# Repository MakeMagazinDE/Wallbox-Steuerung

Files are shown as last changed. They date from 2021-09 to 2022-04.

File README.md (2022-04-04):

GitHub Logo

Maker Media GmbH

***

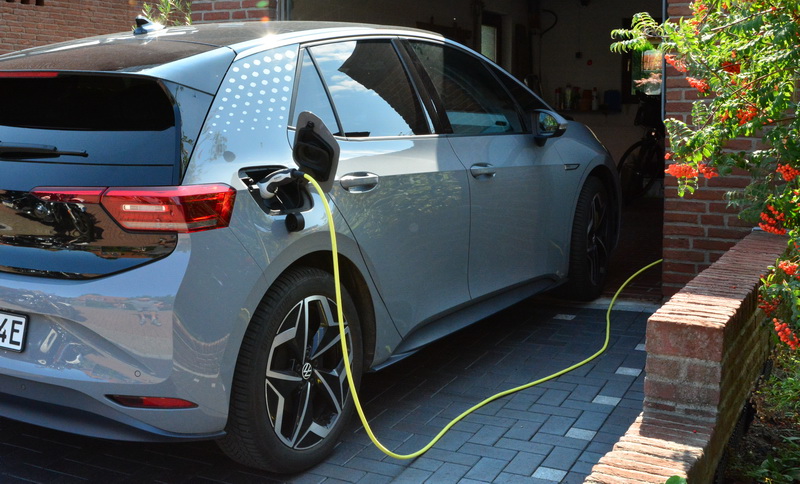
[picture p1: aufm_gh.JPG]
 

# Photovoltaik an der E-Auto-Wallbox

### Überschuss-Laden mit der eigenen Wallbox

Die KfW-Förderung für Wallboxen macht hauseigene Ladeterminals attraktiv wie nie. Wer zudem schon eine Photovoltaik-Anlage installiert hat, kann sein Auto kostenfrei mit Solarstrom laden. Voraussetzung ist allerdings eine intelligente Steuerung – wenn die fehlt, rüstet man einfach unsere ESP8266-Ladeautomatik nach. 

### Dateien:

* eagle pcb (Verzeichnis) - Eagle-Dateien für Platinenversion
* pv_charger_mit_SD_23092021-goe-SW-ab051.4 (Verzeichnis) - Projektdateien für ESP8266 auf Arduino-IDE
* Schaltplan Wemos D1 mini.jpg - Schaltplane, hohe Auflösung wie im Heft abgedruckt

Den vollständigen Artikel mit der Bauanleitung gibt es in der [Make-Ausgabe 5/21 ab Seite 104](https://www.heise.de/select/make/2021/5).

# Photovoltaik an der E-Auto-Wallbox - reloaded

### Überschuss-Laden mit der eigenen Wallbox, Teil 2

Teil 2 in [Make-Ausgabe 2/22 ab Seite 52](https://www.heise.de/select/make/2022/6) ergänzt das Projekt um einen zweiten Lösungsansatz, der ohne zusätzlichen Energiezähler auskommt und stattdessen den aktuellen Verbrauch aus dem "Smart Meter" des Stromanbieters ausliest. Software und Layout finden Sie im Unterordner "Wallbox Teil 2".

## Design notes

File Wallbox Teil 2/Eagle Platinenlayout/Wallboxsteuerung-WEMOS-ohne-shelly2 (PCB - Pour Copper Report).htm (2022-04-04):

## Pour Copper Report

Report Written: | Thursday, March 10, 2022
Design Path: | E:\Dropbox\Heise\Wallbox meets Photovoltaik\Eagle Platinenlayout\Wallboxsteuerung-WEMOS-ohne-shelly2.pcb
Design Title:
Created: | 10.03.2022 10:02:38
Last Saved: | 10.03.2022 12:18:49
Editing Time: | 136 min
Units: | mm (precision 3)

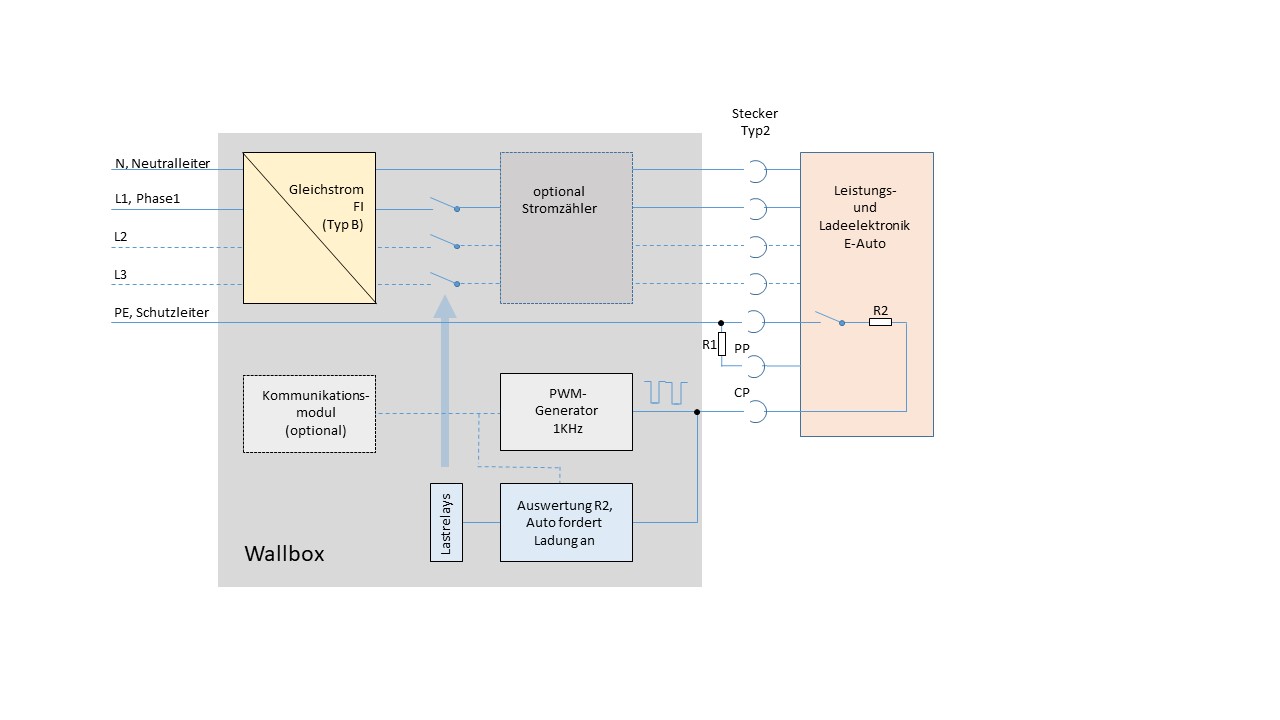
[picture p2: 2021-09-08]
Prinzipschaltung Wallbox.JPG

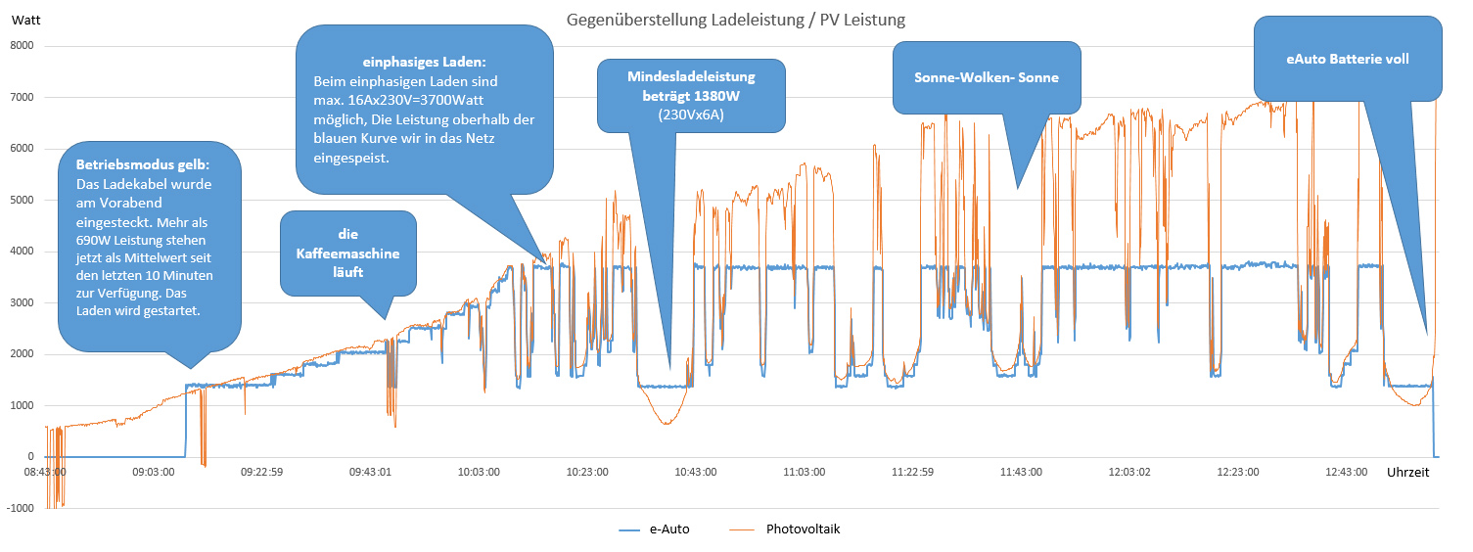
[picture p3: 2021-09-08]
Ladekurve.jpg

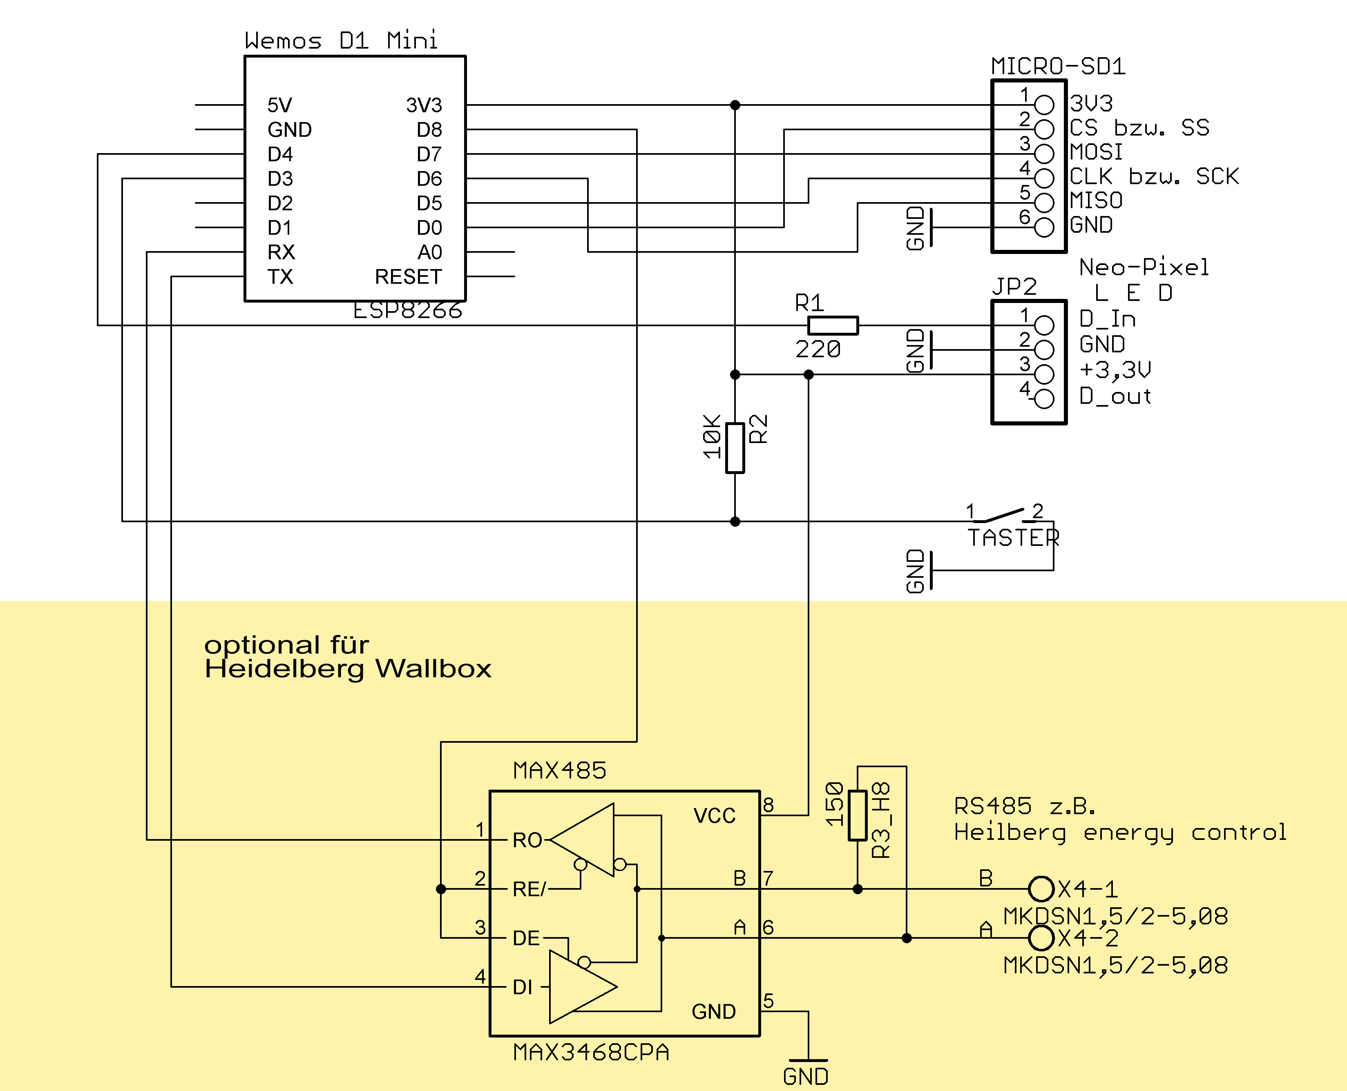
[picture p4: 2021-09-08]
Schaltplan Wemos D1 mini.jpg

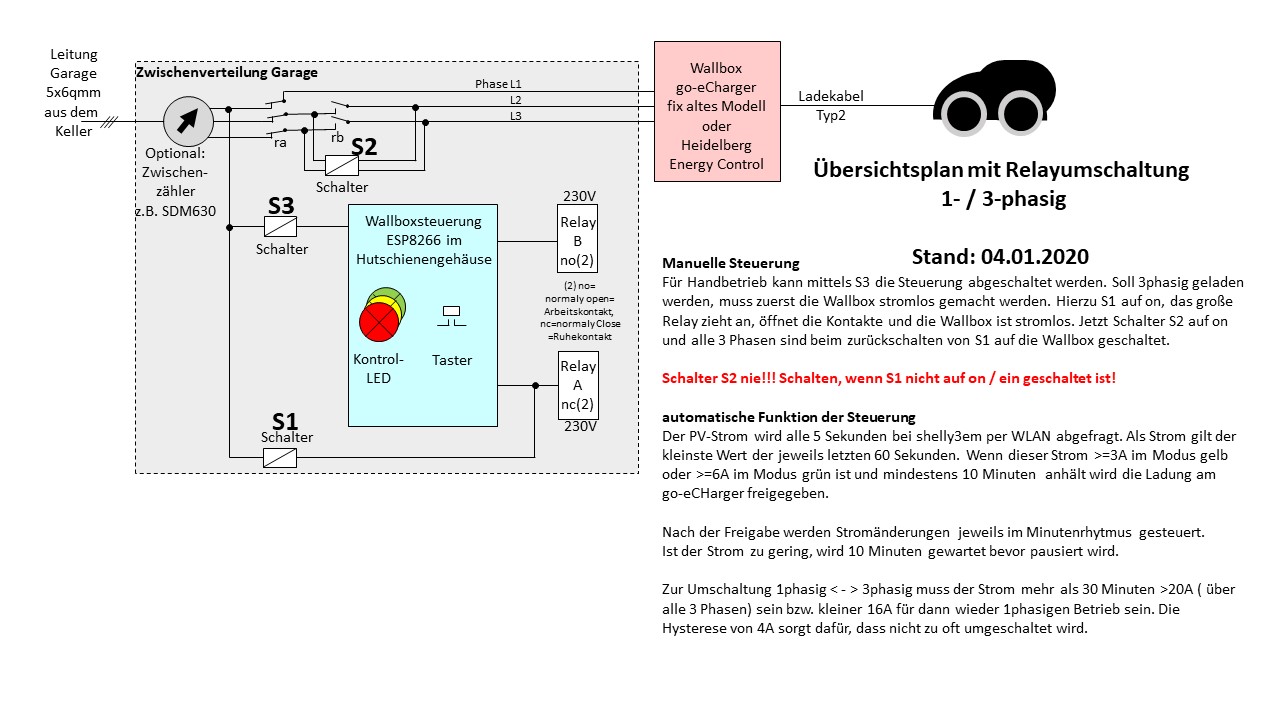
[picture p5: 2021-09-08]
1phasig-3phasig per Relay umschalten.jpg

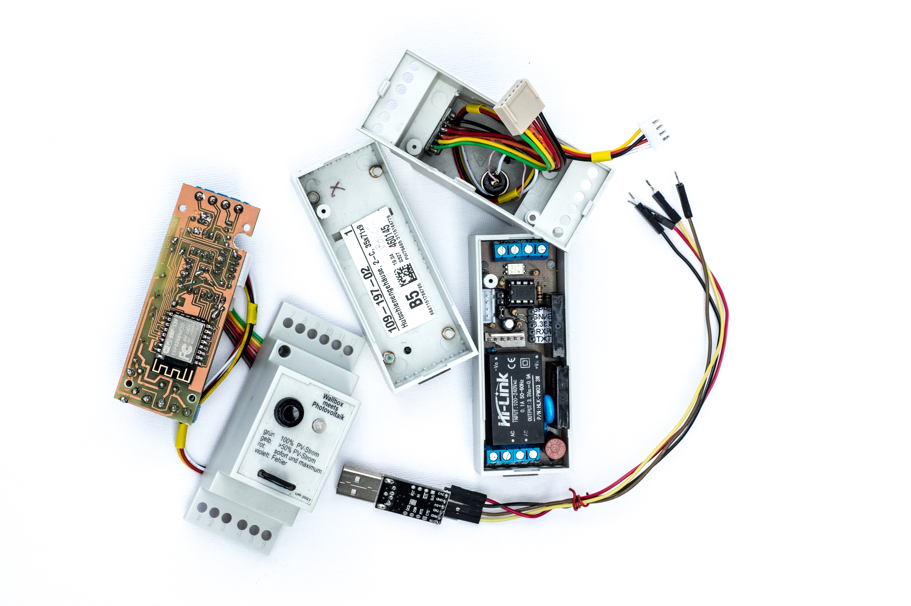
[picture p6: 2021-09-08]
eagle pcb/Wallbox meets PV wei├ƒer Hintergrund.jpg

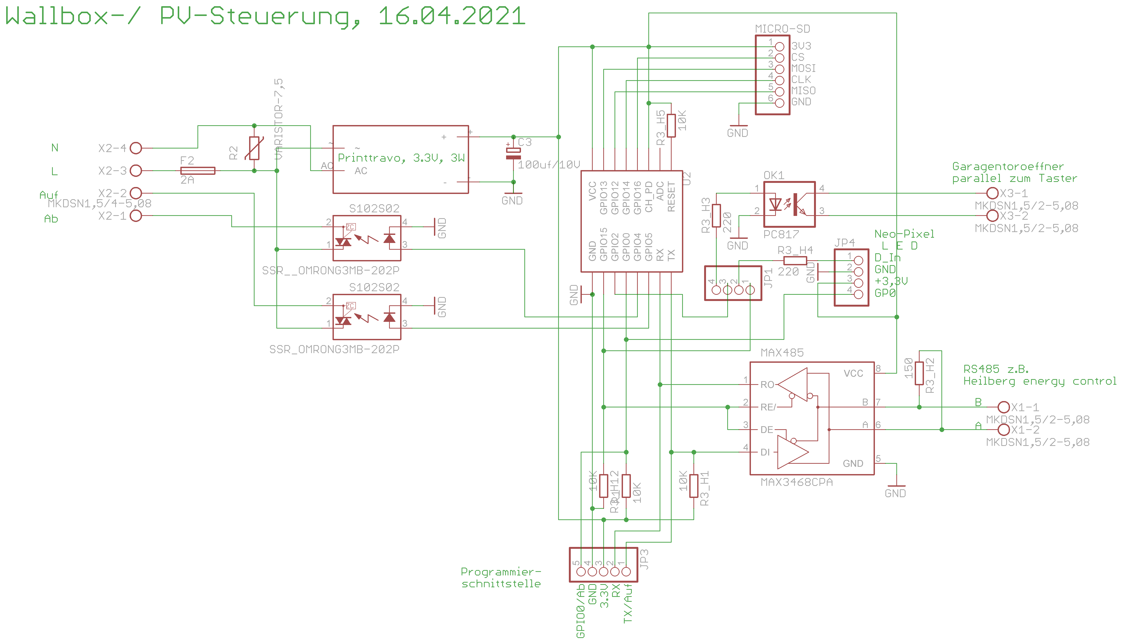
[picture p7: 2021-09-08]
eagle pcb/Schaltplan.png

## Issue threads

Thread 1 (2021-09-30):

Ich bin gespannt…

andig, 2021-09-30:
…wann sich der erste Anwender mit abgebranntem Auto meldet. M.E. gehören Absicherungen in die Schaltung, aber NIE in die Software. Ich würde die Hände von diesem Experiment lassen.

uwe1896, 2021-10-19:
Natürlich ist eine 3-phasige Sicherung vor das shelly 3em zu setzen. Auch andere (Zwischen-) Zähler haben ja keine integrierte Sicherung.

andig, 2021-10-19:
Mir ging es um die fehlende Absicherung von S2 in https://github.com/MakeMagazinDE/Wallbox-Steuerung/blob/master/1phasig-3phasig%20per%20Relay%20umschalten.jpg

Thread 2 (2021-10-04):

Regestrierung des Shelly

Uwesausabeid, 2021-10-04:
Hi, ist die Registrierung des Shelly 3EM beim Hersteller und die Einbindung ins eigene WLan Netz erforderlich?

andig, 2021-10-19:
Mir ging es um
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. Da fehlt jegliche Absicherung in der Hardware.

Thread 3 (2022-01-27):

Phasenumschaltung bei V3 noch nötig?

mprt, 2022-01-27:
Hallo,
Kurze Frage zum Verständnis: Laut aktueller go-e [Anleitung](https://go-e.co/wp-content/uploads/2021/11/go-eCharger-HOME_INSTALLATIONS-UND-BEDIENUNGSANLEITUNG_DE_V3.pdf) beherrscht die Hardware V3 die Phasenumschaltung per App.
Heißt das, dass ich mir den Nachbau damit sparen kann, oder gibt es noch einen Vorteil den ich mit dieser Lösung habe?

Danke!

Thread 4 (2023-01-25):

Läuft das bei jemanden?

ChrisHVL, 2023-01-25:
Hallo Zusammen,
mit der Fernsteuerung der Wallbox ohne Shelly als Überschussladen habe ich kein Problem, da das Auto ja sowieso bei 100% abschaltet.
Mit der Arduino 2.03 IDE habe ich aber jede Menge Fehler in den Bibliotheken.
Was mache ich falsch?
Gibt es einen aktualisierten Code?
Danke!

ChrisHVL, 2023-04-10:
Sehr schade, dass niemand auf die Anfragen beim Make-Magazin reagiert.
Kaufe mir jetzt den go-e - Controller. Der kostet zwar 250€, wird aber funktionieren...

DiyParts, 2024-02-22:
Hallo ChrisHVK! Sehr schade, dass hier niemand vom Make Magazin (Redaktion/ Autor) geantwortet hat!
Ich habe auch einen go-e Charger und PV und mich aus Interesse gerade erstmalig mit Schaltung und Software beschäftigt. Meine Erkenntnisse:
(1) Die Schaltung benötigt man nicht! Es gibt schon für 8€ in der Bucht einen IR Lese-/Sendekopf mit Schmitt-Triggern fertig bestückt. Ein Gehäuse findet man zum Drucken auch, dann sieht das auch nicht so gebastelt aus wie mit dem Flaschendeckel. Den RX Ausgang vom IR Lese-/Sendekopf muss man dann nur noch auf den esp8266 Eingang geben. LED und Taster drumherum - fertig ist die Schaltung.
(2) Ich habe hier einen EMH Zweirichtungszähler von meinem Energieversorger installiert bekommen. Dieser EMH gibt anstatt Textzeichen wie im "Infrarotkopf_pruefprogrammt_26.11.2021.ino" Daten im Hexformat aus. Dass es das auch gibt, ist im Artikel leider nicht beschrieben, das hätte mir helfen können. Jedenfalls hilft das Programm mir so nicht weiter, hier ist nur der einfachste Fall umgesetzt - das Leben hält andere Herausforderungen in der Hinterhand. Die unterschiedlichen Ausgabeformate werden hier prima vorgestellt: https://forum.arduino.cc/t/hello-world-sml-protokoll-auslesen/1199364. Ich habe daraufhin meine Forschung zum IR Kopf eingestellt und werde die Daten anders beschaffen müssen.
(3) Das Prüfprogramm kann man zunächst dafür nutzen, dass man Prüftexte über die Serial monitor view sendet. Dann sieht man schon ganz gut, was passiert, ohne dass der Lesekopf angeschlossen ist.
(4) Ich habe übrigens das Prüfprogramm dahingehend geändert, dass ich die eingelesenen Zeichen direkt auf die Serial Monitor view ausgebe (nach Zeile 54) und nicht erst im Nachhinein in der Funktion puffer_ausgeben(). In meinem Fall wurde der puffer beim Einlesen über den IR Kopf weder richtig angefangen, noch beendet. Daher wurde auch kein Puffer ausgegeben :-/
(5) Kommentare fehlen leider im Prüfprogramm. So auch hier:
#define LOGAREX 4 //D2 = GPIO4
Wenn ich mich nicht irre, soll hier die on board LED an- und ausgeknipst werden. Wäre interessant gewesen, dies anzumerken!!!! Bei meinem Wemos D1 m1n1 Clone sitzt die Led an GPIO2.

DiyParts, 2024-02-26:
Hallo Chris,

ich habe sowieso ein System am Laufen:

- Deye Hybridwechselrichter, Steuerung über CHINT DTSU666

- selbst gebauter Akku mit JKBMS

- Kommunikation zwischen WR und Akku über https://github.com/ArminJo/JK-BMSToPylontechCAN

Ich wollte mit dem vorhandenen IR Kopf „mal schnell“ die Steuerung des go-e ausprobieren, bevor ich eine Steuerung des go-e in das Programm des JK-BMSToPylontechCAN Converters integriere. Das hat leider sowas von gar nicht geklappt 😊

Für mich ist damit aber der Weg vorgegeben: Ich werde den CHINT anzapfen und darüber den go-e charger steuern. Dann bin ich vom Zähler des Energieversorgers unabhängig.

Viele Grüße,

Olaf

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

Closed 2024-10-04.

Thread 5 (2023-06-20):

go-e controller als Alternative

ChrisHVL, 2023-06-20:
Hallo,
ich bin ziemlich enttäuscht, dass keinerlei Reaktion auf meine Anfragen von Autor oder der Redaktion gekommen sind.
Habe mir jetzt den go-e Controller gekauft. Der ist günstig und erhält Support.

Closed 2024-10-04.

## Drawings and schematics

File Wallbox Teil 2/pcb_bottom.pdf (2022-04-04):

C1

# LED8

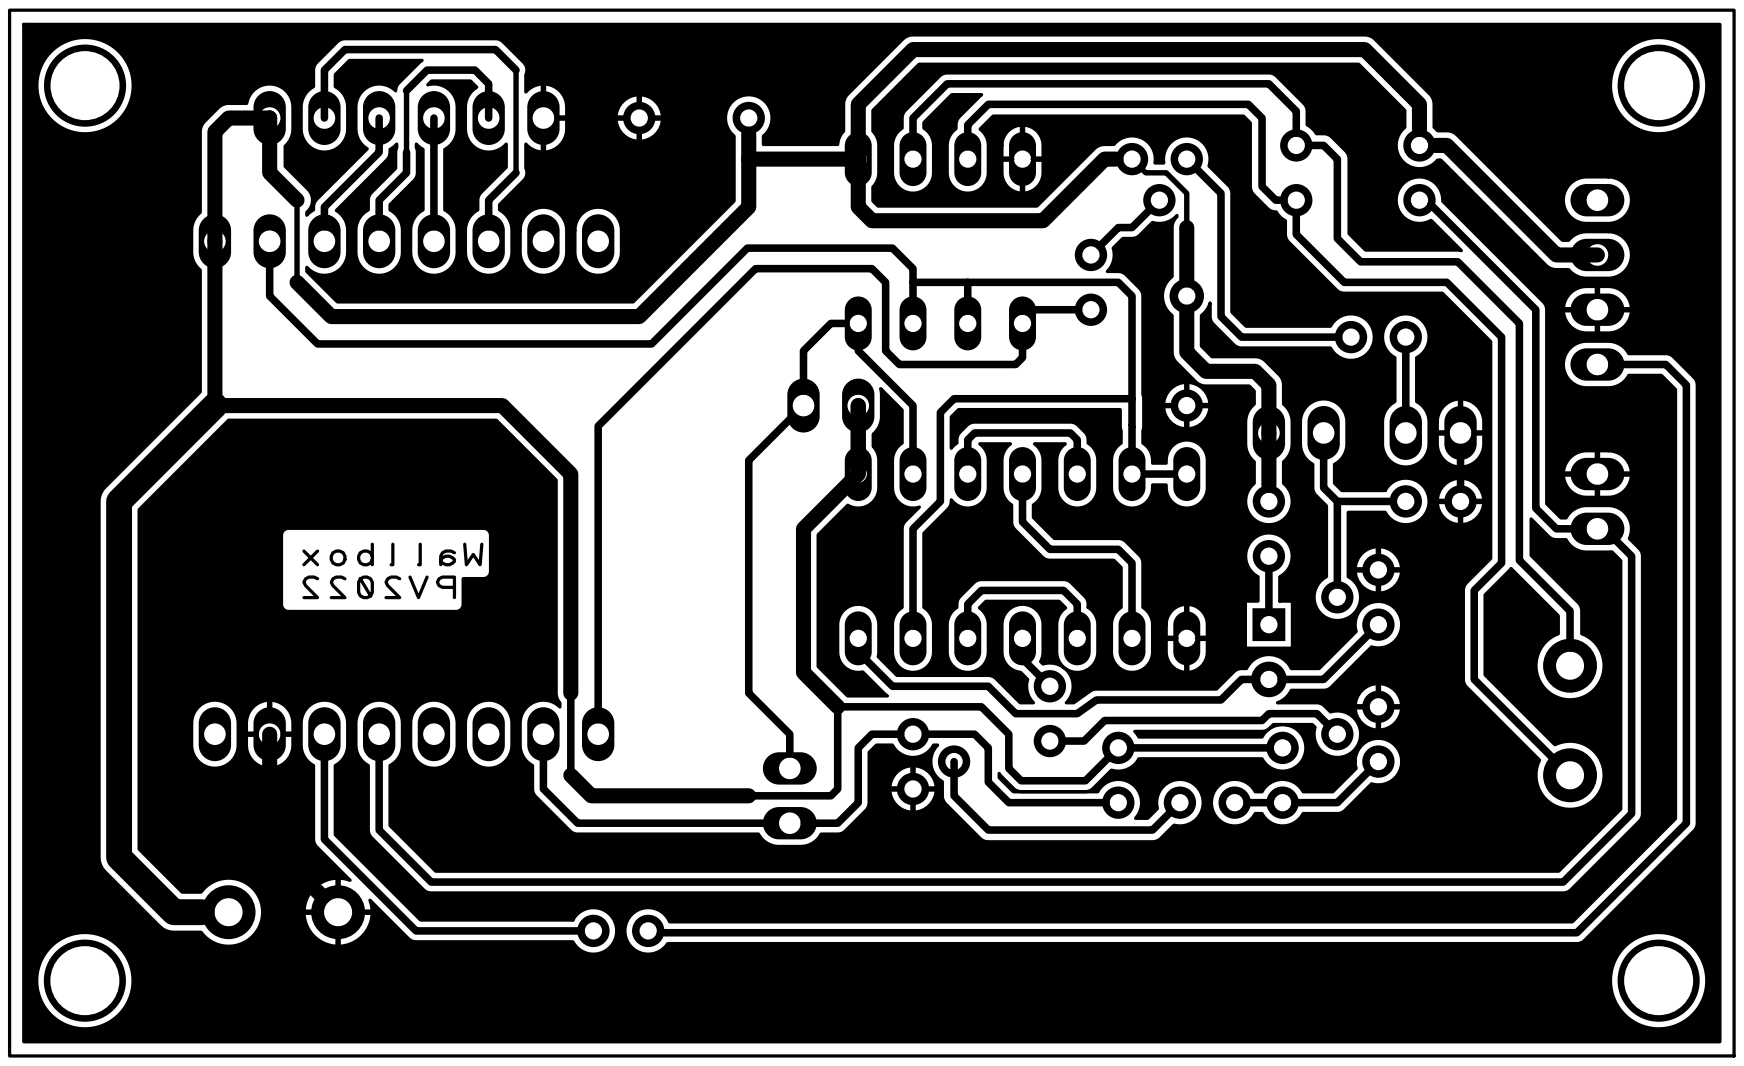
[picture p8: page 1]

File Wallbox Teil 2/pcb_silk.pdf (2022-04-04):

C1

# LED8

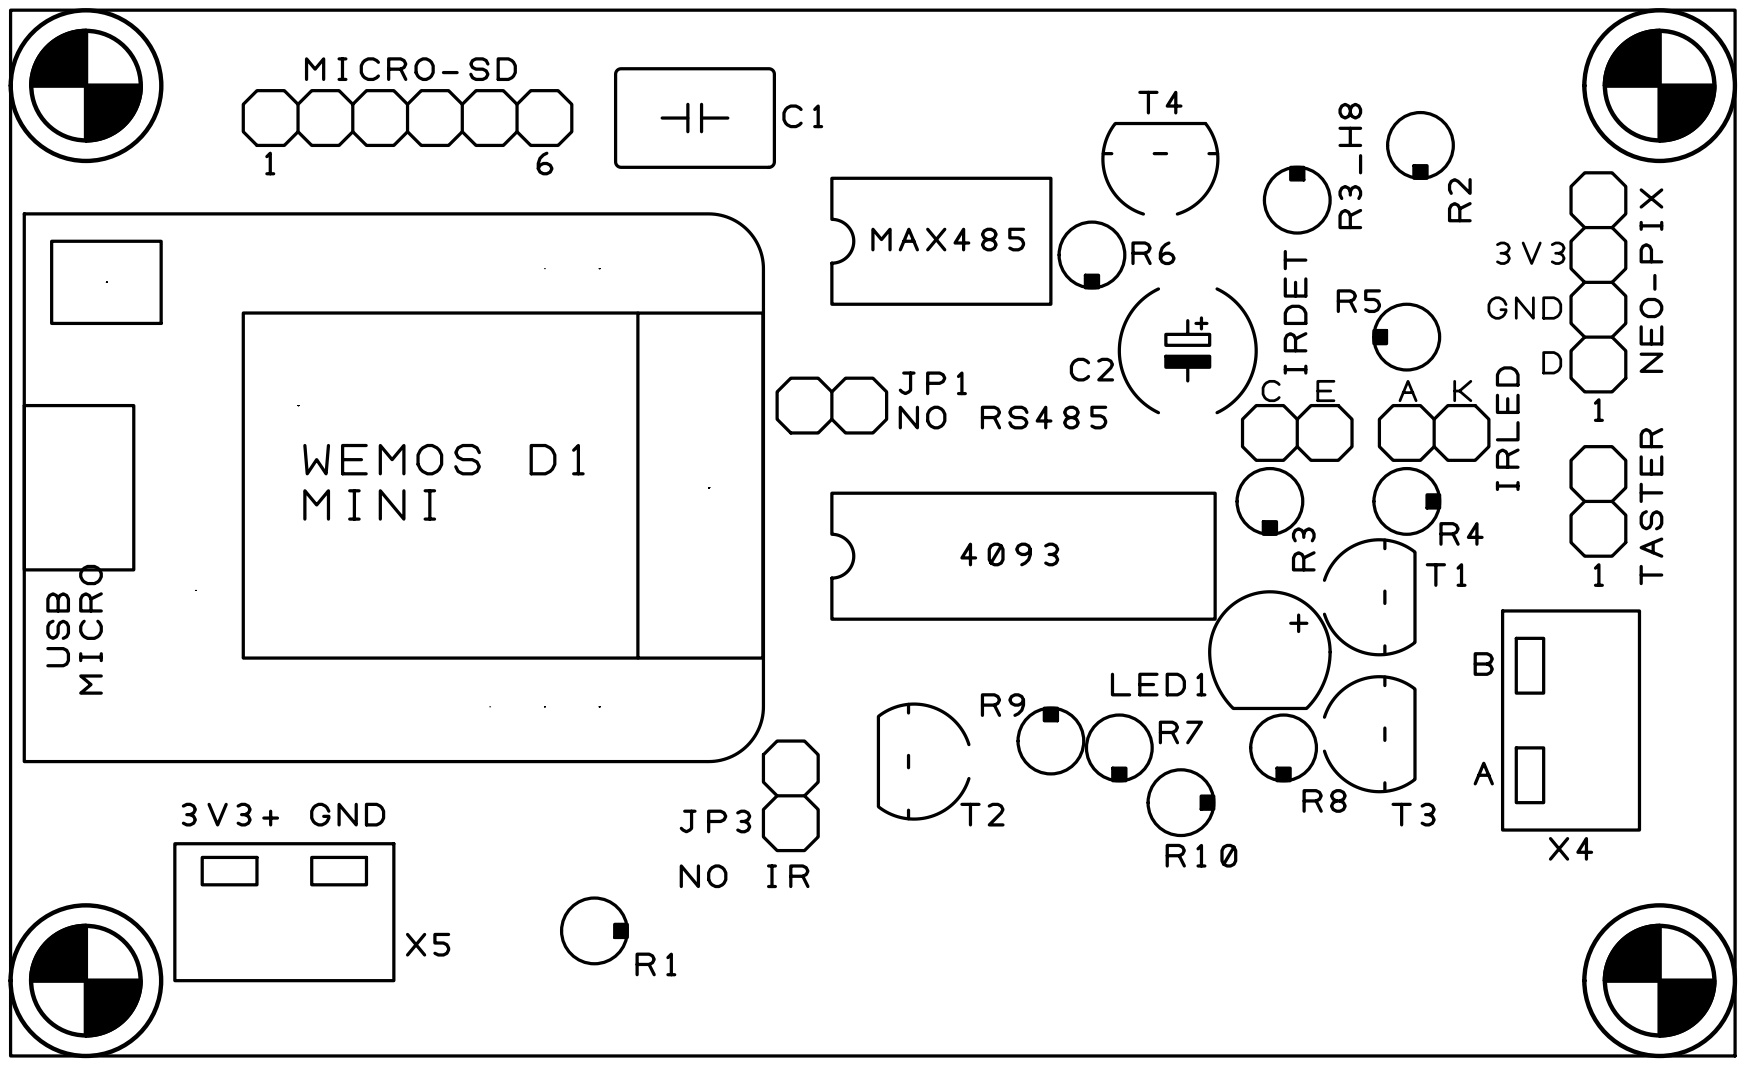
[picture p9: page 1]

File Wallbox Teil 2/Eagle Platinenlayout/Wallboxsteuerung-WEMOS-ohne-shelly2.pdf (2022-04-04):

C1

# LED8


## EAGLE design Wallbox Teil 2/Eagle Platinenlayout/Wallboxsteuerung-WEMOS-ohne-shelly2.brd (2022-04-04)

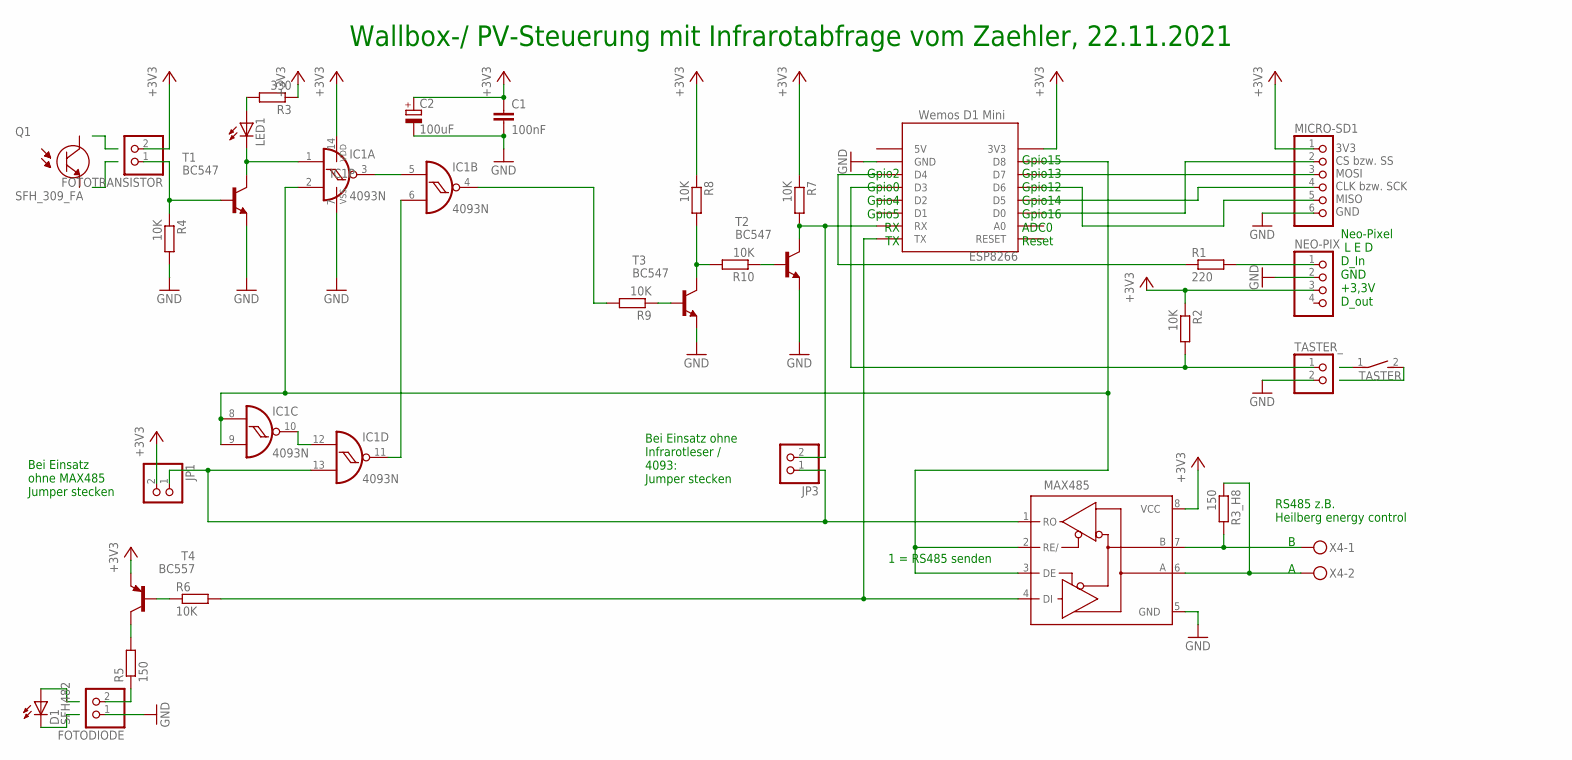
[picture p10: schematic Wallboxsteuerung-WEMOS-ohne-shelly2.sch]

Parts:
C1: 100nF; C050-045X075
C2: 100uF; E5-6
D1: SFH482
ESP8266: Wemos D1 Mini; WEMOS-D1-MINI
FOTODIODE: PINHD-1X2; 1X02
FOTOTRANSISTOR: PINHD-1X2; 1X02
IC1: 4093N; DIL14
JP1, JP3: PINHD-1X2; 1X02
LED1: LED5MM
MAX485: MAX3468CPA; DIL08
MICRO-SD1: PINHD-1X6; 1X06
NEO-PIX: PINHD-1X4; 1X04
Q1: SFH_309_FA; XDCR_SFH_309_FA
R1: 220; 0309V
R2, R4, R6, R7, R8, R9, R10: 10K; 0309V
R3: 330; 0309V
R3_H8, R5: 150; 0309V
T1, T2, T3: BC547; TO92
T4: BC557; TO92
TASTER: DS01E; DS-01
TASTER_: PINHD-1X2; 1X02
X4: MKDSN1,5/2-5,08

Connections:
+3V3: C1.1, C2.+, ESP8266.3V3, FOTOTRANSISTOR.2, IC1.14 (VDD), JP1.2, MAX485.8 (VCC), MICRO-SD1.1, NEO-PIX.3, R2.1, R3.1, R7.1, R8.1, T4.1 (E)
GND: C1.2, C2.-, ESP8266.GND, FOTODIODE.1, IC1.7 (VSS), MAX485.5 (GND), MICRO-SD1.6, NEO-PIX.2, R4.2, T1.1 (E), T2.1 (E), T3.1 (E), TASTER_.2
unnamed: ESP8266.D4, R1.1
unnamed: FOTOTRANSISTOR.1, R4.1, T1.2 (B)
unnamed: IC1.1 (I0), LED1.K (C), T1.3 (C)
unnamed: IC1.3 (O), IC1.5 (I0)
unnamed: ESP8266.D8, IC1.2 (I1), IC1.8 (I0), IC1.9 (I1), MAX485.2 (RE/), MAX485.3 (DE)
unnamed: R5.2, T4.3 (C)
unnamed: IC1.4 (O), R9.2
unnamed: ESP8266.TX, MAX485.4 (DI), R6.2
unnamed: IC1.6 (I1), IC1.11 (O)
unnamed: FOTODIODE.2, R5.1
unnamed: R6.1, T4.2 (B)
unnamed: IC1.10 (O), IC1.12 (I0)
unnamed: ESP8266.RX, JP3.2, R7.2, T2.3 (C)
unnamed: R8.2, R10.2, T3.3 (C)
unnamed: R10.1, T2.2 (B)
unnamed: R9.1, T3.2 (B)
unnamed: LED1.A, R3.2
unnamed: IC1.13 (I1), JP1.1, JP3.1, MAX485.1 (RO)
unnamed: NEO-PIX.1, R1.2
unnamed: ESP8266.D3, R2.2, TASTER_.1
unnamed: ESP8266.D0, MICRO-SD1.2
unnamed: ESP8266.D7, MICRO-SD1.3
unnamed: ESP8266.D5, MICRO-SD1.4
unnamed: ESP8266.D6, MICRO-SD1.5
unnamed: MAX485.7 (B), R3_H8.2, X4.1
unnamed: MAX485.6 (A), R3_H8.1, X4.2

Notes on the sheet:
Wallbox-/ PV-Steuerung mit Infrarotabfrage vom Zaehler, 22.11.2021
3V3 CS bzw. SS MOSI CLK bzw. SCK MISO GND
Neo-Pixel L E D D_In GND +3,3V D_out
B A
RS485 z.B. Heilberg energy control
Bei Einsatz ohne MAX485 Jumper stecken
Bei Einsatz ohne Infrarotleser / 4093: Jumper stecken
Gpio15 Gpio13 Gpio12 Gpio14 Gpio16 ADC0 Reset
Gpio2 Gpio0 Gpio4 Gpio5 RX TX
1 = RS485 senden

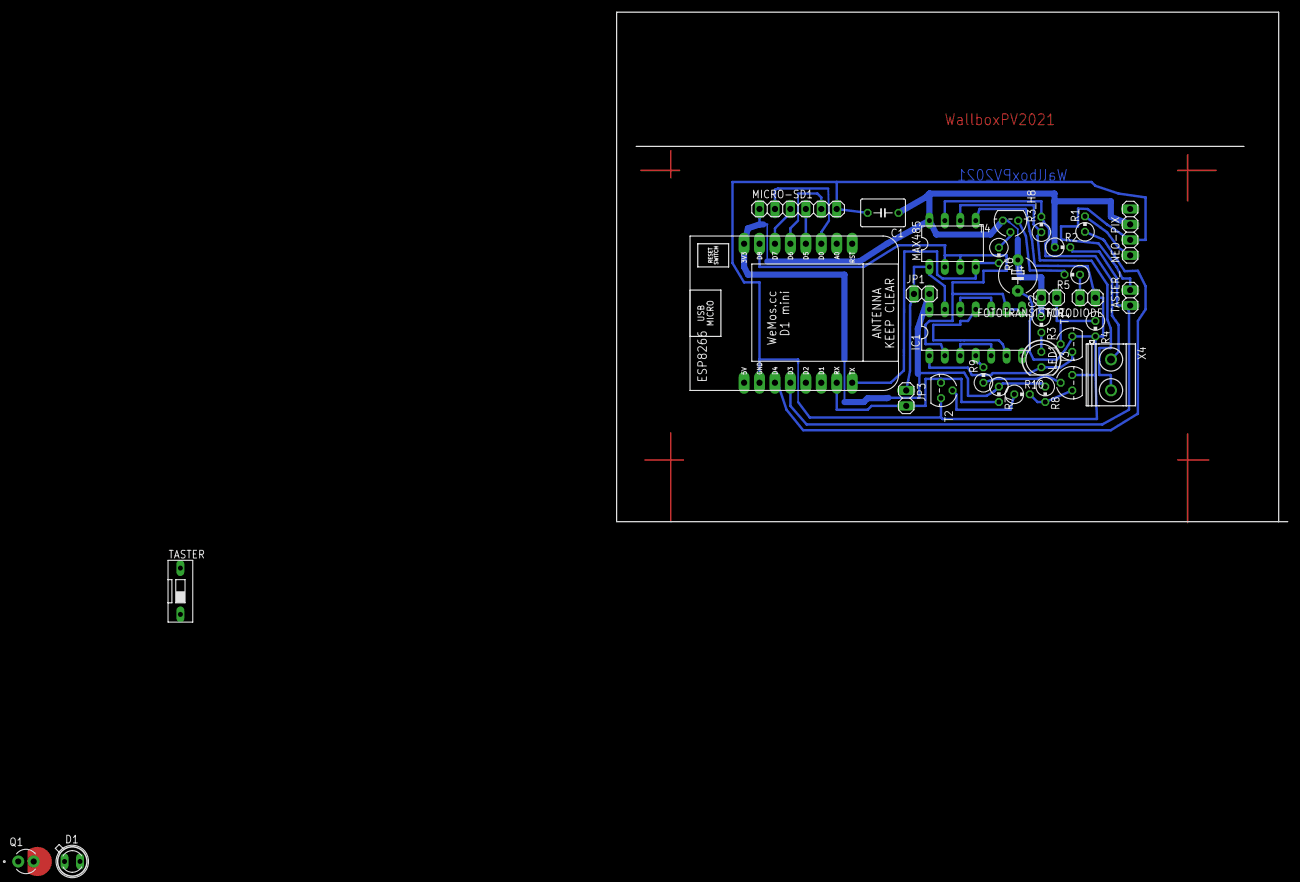
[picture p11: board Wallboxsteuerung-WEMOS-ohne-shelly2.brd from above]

Board: 2 copper layers, 110.4 x 83.8 mm, 32 parts (0 on the bottom side), 28 nets.

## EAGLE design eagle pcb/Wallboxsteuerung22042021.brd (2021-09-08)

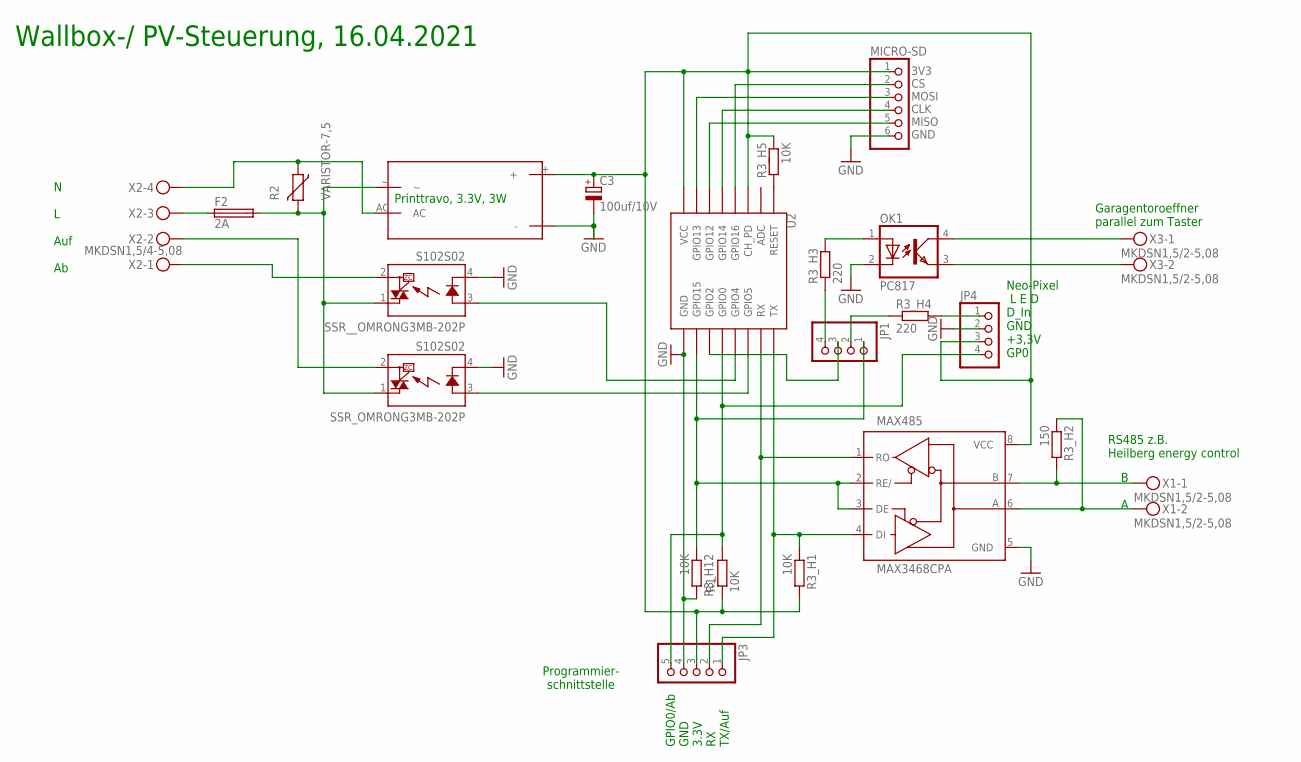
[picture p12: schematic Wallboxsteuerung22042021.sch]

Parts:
C3: 100uf/10V; E2,5-7
F2: 2A; LITTLEFUSE
JP1, JP4: PINHD-1X4; 1X04
JP3: PINHD-1X5; 1X05
MAX485: MAX3468CPA; DIL08
MICRO-SD: PINHD-1X6; 1X06
OK1: PC817; DIL04
PRINTTRAFO3.3V,_3W: PRINTTRAFO
R1: 10K; 0207/7
R2: VARISTOR-7,5; R-7,5
R3_H1, R3_H5: 10K; 0309V
R3_H2: 150; 0309V
R3_H3, R3_H4: 220; 0309V
R3_H12: 10K; 0207/2V
SSR_OMRONG3MB-202P: S102S02; S202S02
SSR__OMRONG3MB-202P: S102S02; S202S02
U2: ESP12SMD; ESP12-SMD
X1, X3: MKDSN1,5/2-5,08
X2: MKDSN1,5/4-5,08

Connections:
GND: C3.-, JP3.4, JP4.2, MAX485.5 (GND), MICRO-SD.6, OK1.2 (C), PRINTTRAFO3.3V,_3W.-, R3_H12.2, SSR_OMRONG3MB-202P.4 (K), SSR__OMRONG3MB-202P.4 (K), U2.GND
unnamed: SSR_OMRONG3MB-202P.3 (A), U2.GPIO4 (GPIO5)
unnamed: F2.1, X2.3
unnamed: SSR__OMRONG3MB-202P.3 (A), U2.GPIO5 (GPIO4)
unnamed: SSR_OMRONG3MB-202P.2 (DS2), X2.2
unnamed: R3_H5.2, U2.RESET
unnamed: JP3.2, MAX485.1 (RO), U2.RXD0 (RX)
unnamed: PRINTTRAFO3.3V,_3W.AC, R2.1, X2.4
unnamed: JP4.1, R3_H4.2
unnamed: JP1.3, U2.GPIO2
unnamed: MICRO-SD.4, U2.GPIO14
unnamed: JP3.5, JP4.4, R1.2, U2.GPIO0
unnamed: F2.2, PRINTTRAFO3.3V,_3W.~, R2.2, SSR_OMRONG3MB-202P.1 (DS1), SSR__OMRONG3MB-202P.1 (DS1)
unnamed: SSR__OMRONG3MB-202P.2 (DS2), X2.1
unnamed: MICRO-SD.5, U2.GPIO12
unnamed: MICRO-SD.3, U2.GPIO13
unnamed: JP1.4, R3_H3.1
unnamed: MICRO-SD.2, U2.GPIO16
unnamed: JP3.1, MAX485.4 (DI), R3_H1.1, U2.TXD0 (TX)
unnamed: OK1.1 (A), R3_H3.2
unnamed: MAX485.7 (B), R3_H2.2, X1.1
unnamed: MAX485.6 (A), R3_H2.1, X1.2
unnamed: OK1.3 (EMIT), X3.2
unnamed: OK1.4 (COL), X3.1
unnamed: JP1.2, R3_H4.1
unnamed: JP1.1, MAX485.2 (RE/), MAX485.3 (DE), R3_H12.1, U2.GPIO15
unnamed: C3.+, JP3.3, JP4.3, MAX485.8 (VCC), MICRO-SD.1, PRINTTRAFO3.3V,_3W.+, R1.1, R3_H1.2, R3_H5.1, U2.CH_PD, U2.VCC

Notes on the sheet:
Printtravo, 3.3V, 3W
N L Auf Ab
Wallbox-/ PV-Steuerung, 16.04.2021
GPIO0/Ab GND 3.3V RX TX/Auf
Programmier- schnittstelle
3V3 CS MOSI CLK MISO GND
B A
Garagentoroeffner parallel zum Taster
RS485 z.B. Heilberg energy control
Neo-Pixel L E D D_In GND +3,3V GP0

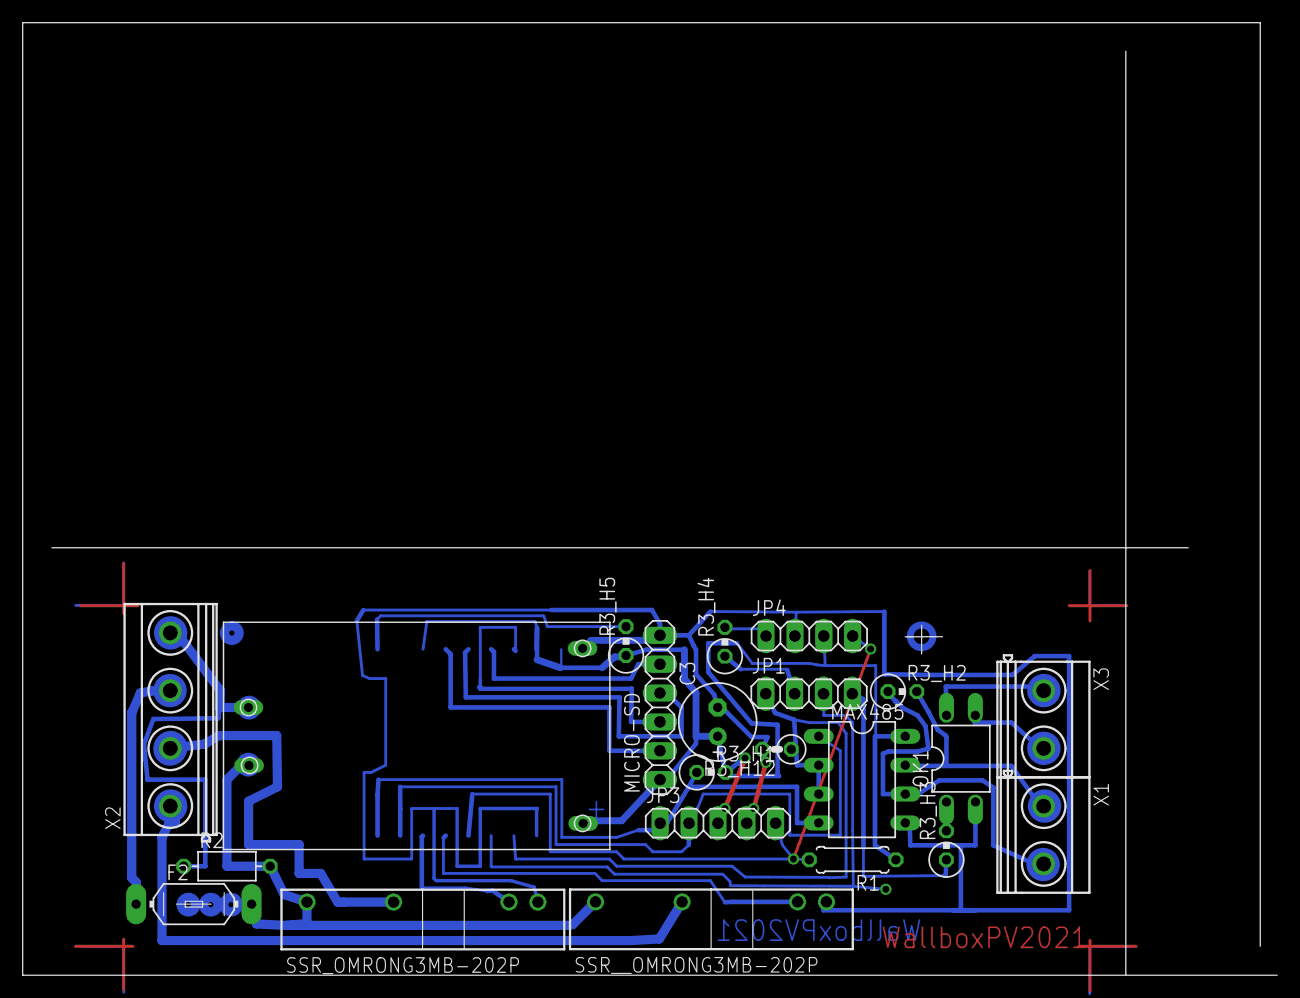
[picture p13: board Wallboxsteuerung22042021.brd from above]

Board: 2 copper layers, 110.4 x 83.8 mm, 23 parts (1 on the bottom side), 27 nets.

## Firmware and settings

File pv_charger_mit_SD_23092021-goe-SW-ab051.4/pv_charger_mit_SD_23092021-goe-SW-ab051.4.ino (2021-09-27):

#define vers "Version: 22.08.2021"
/**Wallboxsteuerung in Kombination mit Photovoltaik 06.05.2021, <<<< 192.168.178.41 >>>>
*/
//#include <Arduino.h> wird bereits mit arduinoOTA.h (siehe ota.h)inkludiert
//OTA
//OTA *** in der Arduino IDE Board auf  "NodeMCU 1.0(ESP-12E Module)" und ***
//OTA *** Flash Size auf "4MB (FS:2MB OTA: 1019KB)" stellen               ***
//OTA
#include "ota.h" 
#include <ESP8266WiFi.h>
//#include <ESP8266WiFiMulti.h> //#################################################################################
#include <ESP8266HTTPClient.h>
#include <WiFiClient.h>
#include <ESP8266WebServer.h> //*********Server
WiFiServer server(80);        //*********Server
WiFiClient client1;           //*********Server
#include <ArduinoJson.h>
#include <Adafruit_NeoPixel.h> //Mehrfarbled
#include <SD.h> //für SD Card, (CLK,MISO,MOSI,SS) 14,12,13,15oder16 bzw. D5, D6, D7, D8oder?
#include <TimeLib.h>
#define CS_PIN  16 //D8=15 ist bei MP3 Benutzung belegt, dann NICHT verwendenfür SD Card
File mySD; //für SD Card
#define taster 0 //Built in Taster auf Pin Gpio0
#define garagentorpin 15 // Ansteuerung Relais bzw. optoKoppler zum Garagentor öffnen, doppelt belegt mit RS485 Umschaltung
#define NEOPIXELPIN 2 //  Neopixel WS2811 (LED)   
#define RS485_Richtung 15 //Umschaltung MAX485 halbduplex zwischen senden und empfangen, dopplet belegt mit NEO-Pixel
#define relay_3ph 4 //Relay welches die Wallbox mit allen Phasen vom Netz trennt
#define relay_2ph 5 //Relay welches 2 Phasen dazu schaltet (von ein- auf dreiphasig)
#define mn 60 //Minimum
#define mx 61 //Maximum
#define mw 62 //Mittelwert
Adafruit_NeoPixel pixels(1, NEOPIXELPIN, NEO_GRB); // 1 steht für ein Neopixel (also die Anzahl)
#include "uwesserver.h"       // erledigt den Webseiteaufbau und Abfrage
#include "Telnet2Serial.h" ermöglicht die Ausgabe von Werten via Telnet auf Port 23
char ssid[18], password[18], ip_shelly[18], ip_goe[18]; // Werte werden aus der config.txt eingelsesen
int wb, st, eindrei, laden_aktiv=0;                                    // Werte werden aus der config.txt eingelsesen
char telnet_buf[200], uhrzeit[6];
float w_akt1[12];
boolean  ta_pin_ruhe, fl_ta_pin=false, fl_relay=false;
int minmaxmiw[63], lfd_nr_mmm=0; //Hier werden Minimum. Maximum und Mittelwerte der letzten 60 Messungen gebildet 19042021$$$$$$$$$$##############
int led_flag=1,led_puls=0,led_beat_ti[]={300,80,10}, fl_timer[]={0,0,1,2}, ladestrom_ist, spannung_L1, spannung_L2, car_old,ladestrom_old=0/*betriebsmodus=0 in uwesserver.h*/; 
int eingabe=0, betriebsmodus_old=0, ladestrom=0;
//betriebsmodus, blaue LED auf uC: 0=blinkt langsam,sofort laden mit max. Leistung, 
//                                 1=blinkt Sek.Rytm. min. 50% akt. Photovoltaik (PV), 
//                                 2=blinkt schnell min 100% PV
unsigned long led_previousmicros = 0, ti_taster, ti_timer[4], shelly3em_lfd_nr=0, led_interval = 10000, tme, t_unixtime;
//*********************************************************************************
void setup() {
  pixels.begin(); // INITIALIZE NeoPixel strip object (REQUIRED)
  pixels.clear(); // NEOPIXDEL LED: Set all pixel colors to 'off'
  if(!SD.begin(CS_PIN)) multi_led(4);//{Serial.println(F("Card Mount Failed"));while(1){yield;}}// (CLK,MISO,MOSI,SS)) 14,12,13,16
  if(config_von_sd()==false) multi_led(4);  
  if(wb==2) {
    Serial.begin(19200, SERIAL_8E1);  //8Bit + even Parity bei Heidelbergwallbox
    pinMode(RS485_Richtung, OUTPUT);
    digitalWrite(RS485_Richtung, LOW);
  }
  else Serial.begin(115200); //Serial.println("\nLadekurve der Wallboxsteuerung in Kombination mit Photovoltaik, Version 22.08.2021\n");
  for(int i=0; i<12;i++) w_akt1[i]=-10000.0; //Array zum Speichern des Minimalwertes der letzten 12 Abfragen initialisieren
  for(int i=0;i<63;i++) minmaxmiw[i]=0; //Array für min, max, mw Ermittlung auf Null setzen 
  WiFi.mode(WIFI_STA);
  WiFi.begin(ssid, password); //Serial.println("\nConnecting to FRITZ!UWE");
  while (WiFi.status() != WL_CONNECTED) delay(500); 
  //Serial.print("\nconnected, address="); Serial.println(WiFi.localIP());
  //pinMode(LED_BUILTIN, OUTPUT);
  pinMode(taster, INPUT_PULLUP);
  pinMode(garagentorpin, OUTPUT);
  digitalWrite(garagentorpin, LOW);
  pinMode(relay_3ph, OUTPUT);
  pinMode(relay_2ph, OUTPUT);
  digitalWrite(relay_3ph, LOW);
  digitalWrite(relay_2ph, LOW);
  ta_pin_ruhe = digitalRead(taster);
  server.begin(); //*********Server
  multi_led(0);delay(500);multi_led(1);delay(500);multi_led(2);delay(500);multi_led(3);delay(500);multi_led(4);delay(500); //Farbenspiel
  multi_led(0);   // NEOPIXDEL LED auf rot = Betriebsmodus "nur Netz" 
  timer(2,1); //Timer2 initialisieren, 30-Minutentimer, wird fuer Umschaltung 3-phasig / 1-phasig verwendet
  uwes_ota_start();     //OTA OTA OTA OTA OTA OTA OTA OTA OTA OTA OTA OTA OTA OTA OTA

  sprintf(telnet_buf,"\nSSID %s, Password (1.Z.) %c..., IP Shelly %s, IP Go-e %s, wb: %d, st: %d, eindrei: %d\n\r", ssid,password[0], ip_shelly, ip_goe, wb, st, eindrei);
  telnet_write(telnet_buf);
  Serial.print(telnet_buf);

}
//*********************************************************************************
void loop() {
  int car;
  //while (Serial.available() > 0) {int e = Serial.parseInt();if(e!=0) {Serial.printf("Eingelesen: %d\n",e);eingabe=e;}}// zum Testen
  ArduinoOTA.handle(); //OTA OTA OTA OTA OTA OTA OTA OTA OTA OTA OTA OTA OTA OTA OTA
  if(tasterabfrage()==1) {
    betriebsmodus++;
    if(betriebsmodus>=3) betriebsmodus=0;
  }
  if(betriebsmodus != betriebsmodus_old) {
    betriebsmodus_old = betriebsmodus;
    multi_led(betriebsmodus); //LED NEOPIXEL WS2811 ansteuern
  }
  //led_beat(led_beat_ti[betriebsmodus]); //10=sehr schnell, 80=sekundenRythmus, 400=gemütlich
  if(timer(0,5000)==true) {             //alle 5 Sekunden go-echarger und shelly 3em abfragen  
    solar=int (shelly3em_status()); //Shelly3em abfragen, aktuelle Leistung als Integer in Watt
    //solar=eingabe; //zum Testen ###################################################################################
    car  =wallbox("egal", -1); // Parameter -1 fragt nur den Status ab, ohne Werte zu setzen 
    if(solar > -30000 && car > -30000) ladestrom=laden(car); // Werte von kleiner -30.000 sind Fehlermeldungen
    else {
      timer(3,2);
      multi_led(4); //LED ist für 2 Sekunden violett um gestörten Zugriff auf shelly3em oder go-echarger anzuzeigen
    }
    if( timer(3,2000)==true) multi_led(betriebsmodus); //... und wieder "Normalmodus
  }
  WiFI_Traffic(); //falls sich ein Client verbunden hat HTML ausgeben und Antwort einlesen
}
//*********************************************************************
int laden(int car) {
  if(car==1) car_old=1;
  ladestrom = solar *(-1)/230;                                        // Leistung der PV geteilt durch Spannung (230Volt) = Ampere
  if(eindrei==3) ladestrom=ladestrom/3;                               // es wird ausschließlich 3-phasig geladen (Parameter eindrei von SD)
  minmaxmiw[lfd_nr_mmm++%60]=ladestrom;                               // den aktuellen Ladestrom speichern um min, max, mittelw bilden zu können
  switch(betriebsmodus) {
    case 0: {                                                         // sofort laden, PV egal, LED=rot
      ladestrom=48;                                                   // Strom auf allen drei Phasen, 3x16=48
      break;
    }
    case 1: {                                                         // mindestens 50% PV, sonst kein Laden, LED=gelb
      if(ladestrom >=3&&ladestrom <6) ladestrom=6;                    // weniger als 6 AMpere geht nicht beim Laden 
      if(ladestrom <3) ladestrom = 0;                                 // bei weniger als 50% von der PV kein Laden 
      break;
    }
    case 2: {                                                         // mindestens 100% PV, sonst kein Laden, LED=grün 
      if(ladestrom<6) ladestrom=0;
      break;
    }
  } //ende Switch                                                     // switch-case Ende
  if(ladestrom !=0) {
    if(ladestrom <=16) dreiphasig(false);
    if(ladestrom > 20) dreiphasig(true);
    if(fl_relay==true) {
      ladestrom = ladestrom /3; //durch 3 weil dreiphasig
      if(ladestrom < 6) ladestrom=6;                                  // kann noetig werden, wenn noch auf 3-phasig geschaltet ist
    }
    if(ladestrom>16) ladestrom=16;                                    // maximal 16 Ampere Ladestrom
    if(ladestrom_old != ladestrom) {
      car=wallbox("amx",ladestrom);                                   // Ladestrom setzen
      ladestrom_old = ladestrom;
    }
    if(car_old==1&&car!=1) {                                          // findet statt, wenn das Ladekabel gesteckt wird
      car_old=car;
      car=wallbox("alw",1);                                           // Laden starten
      sprintf(telnet_buf,"Laden starten über car_old, alw=1 \n\r\0");  telnet_write(telnet_buf);
    }
    if(timer(1,600000) == true) {                                     // alle 10 Min.
      int mw1=mmm(mw); //Mittelwert der letzten 60 Werte 
      if( (mw1>=6&&betriebsmodus==2) || (mw1>=3&&betriebsmodus==1)) { // Wenn Mittelwert der letzten Messungen drüber waren das Laden starten 
        car=wallbox("alw",1);                                         // Laden starten
        sprintf(telnet_buf,"alw=1\n\r\0");  telnet_write(telnet_buf);
       } 
    }
  }
  else {
    dreiphasig(false);
    if(ladestrom_old >6) { //bis zum endgültigen beenden der Ladung Strom auf das Minimum von 6A stellen
      car=wallbox("amx",6); // Ladestrom setzen
      ladestrom_old = 6;
    }
    if(timer(1,600000)==true) {       // alle 10 Min.
      int mw1=mmm(mw); //Mittelwert der letzten 60 Werte 
      if( (mw1<6&&betriebsmodus==2) || (mw1<3&&betriebsmodus==1)) {  //Wenn Mittelwert der letzten Messungen drunter waren das Laden stoppen 
        car=wallbox("alw",0);       // Laden unterbrechen
        ladestrom_old=0;            // damit es beim Naechsten alw=1 dann auch wirklich gleich los geht
        sprintf(telnet_buf,"alw=0\n\r\0");  telnet_write(telnet_buf);
      } 
    }
  }
  sprintf(telnet_buf,"%04d.%02d.%02d;%02d:%02d:%02d;%2dAsoll;%5dPV;%1dcar;%2dLS;%2d=;%2d<;%2d>;%db;%4dWb;%2dAist;%dR;%4ds;%3dx\n\0",
               year(t_unixtime), month(t_unixtime), day(t_unixtime), hour(t_unixtime), minute(t_unixtime),second(t_unixtime),
               ladestrom,solar*(-1),car,minmaxmiw[(lfd_nr_mmm-1)%60],mmm(mw),mmm(mn),mmm(mx),betriebsmodus,leistung,
               ladestrom_ist,fl_relay,(ti_timer[2]+1800000-millis())/1000,(ti_timer[1]+600000-millis())/1000);
  sd(telnet_buf,t_unixtime); //auf SD Karte schreiben
  strcat(telnet_buf,"\r");telnet_write(telnet_buf);
  return(ladestrom);
}  
//*********************************************************************
boolean dreiphasig(boolean dreiph) {
  if(timer(2, 1800000)==true && eindrei==2) { //1'800.000 entspricht 30 Minuten, eindrei==2 bedeudet umschalten zwischen ein- und dreiphasig erlaubt
    if(ladestrom_ist >50 && dreiph==true && fl_relay==false) {  //Ladestrom_ist: Beispiel 50 = 5,0A;  89=8,9 Ampere
      relay_schalten(true);                                     //Ladestrom_ist wird genommen um zu prüfen, dass Auto tatsächlich lädt
      fl_relay=true;
      timer(2,1); //Timer neu starten
    }
    if(dreiph==false && fl_relay==true) {
      relay_schalten(false);
      fl_relay=false;
      timer(2,1); //Timer neu starten
    }
  }
}
//*********************************************************************
void relay_schalten(boolean an) {
  wallbox("alw",0);       // Laden unterbrechen MUSS noch getestet werden$$$$$$$$$$$$$$$$$$$$$$$$$$$$$$$$$$$$$$$$$$$$$$$$$$$$
  delay(3000);                  // Laden unterbrechen MUSS noch getestet werden$$$$$$$$$$$$$$$$$$$$$$$$$$$$$$$$$$$$$$$$$$$$$$$$$$$$
  sprintf(telnet_buf,"3ph-Rel: %d\n\r\0",HIGH);  telnet_write(telnet_buf);
  if(wb!=1) {
    digitalWrite(relay_3ph, HIGH); // go_echarger mit allen 3-Phasen stromlos schalten
    delay(500);
    if(an==true) {
      digitalWrite(relay_2ph, HIGH); //2 Phasen dazu schalten
      sprintf(telnet_buf,"2ph-Rel: %d\n\r\0",HIGH);  telnet_write(telnet_buf);
      //Serial.printf("2ph-Rel: %d\n",HIGH);
    }
    else {
      digitalWrite(relay_2ph,  LOW); //2 Phasen abschalten
      sprintf(telnet_buf,"2ph-Rel: %d\n\r\0",LOW);  telnet_write(telnet_buf);
    }
    delay(500);
    digitalWrite(relay_3ph,  LOW); // go_echarger mit allen 3-Phasen wieder anschalten
    sprintf(telnet_buf,"3ph-Rel: %d\n\r\0",LOW);  telnet_write(telnet_buf);
    delay(6000); // Go-echarger braucht Zeit für einen Neustart
  }
  else {
    if(an==true) wallbox("fsp",0); //der go-echarger schaltet mit dem Befehl fsp zwischen 1- und 3-phasig um
    else wallbox("fsp",1);         //fsp=1 1-phasig und fsp=0 3-phasig
    delay(500);
  }
  for(int n=0;n<15;n++) {         // Laden wieder starten, MUSS noch getestet werden$$$$$$$$$$$$$$$$$$$$$$$$$$$$$$$$$$$$$$$$$$$$$$$$$$$$
    if(wallbox("alw",1)<0) delay(500); 
    else break;
  }
  //while(wallbox("alw",1)<0) delay(500);       // Laden wieder starten, MUSS noch getestet werden$$$$$$$$$$$$$$$$$$$$$$$$$$$$$$$$$$$$$$$$$$$$$$$$$$$$
  //wallbox("alw",1);
  wallbox("amx",ladestrom);                                   // Ladestrom setzen
  ladestrom_old = ladestrom;
}
//*********************************************************************
//mit dauer=0 wird timer initialisiert, mit dauer=1 wird Timer gestartet, nach Ablauf findet kein Rücksetzen bzw. neu "aufziehen" statt
//mit dauer=2 wie bei 1, kommt aber nur einmal mit true zurück
//wenn die Zeit "dauer" in ms um ist, return true, sonst false
boolean timer(int nr, unsigned long dauer) { 
  if(dauer<=2) {
    fl_timer[nr] = int (dauer);
    ti_timer[nr] = millis();
    return(false);
  }
  else {
    if((ti_timer[nr]+dauer) > millis()) return (false);
    else {
      if(fl_timer[nr]<=2) {
        if(fl_timer[nr]==2) fl_timer[nr]=3;
        if(fl_timer[nr]==0) ti_timer[nr]=millis();
        return(true);
      }
    return (false);
    }
  }
  //return(false); 
}
//*********************************************************************
int tasterabfrage() {
  int ta_pin=digitalRead(taster);
  if(ta_pin!=ta_pin_ruhe && fl_ta_pin==false) {
    fl_ta_pin=true;
    ti_taster=millis();
  }
  if(ta_pin==ta_pin_ruhe) {
    fl_ta_pin=false;
    return(-1);
    
  }
  if(ta_pin != ta_pin_ruhe && fl_ta_pin ==true) {
    unsigned long ti=millis()-ti_taster;
    if(ti<=5) return(0);                //entprellen
    if(ti>=5&&ti<2500) {
      ti_taster = ti_taster -3000;      //damit nur einmal return(1) kommt
      ti_timer[1]=millis()-600000;      //ti_timer läuft beim 1. Aufruf auf true, danach alle 10 Minuten
      //led_flag=1;led_puls=0;led_previousmicros = 0;led_interval = 10000;//LED-Beat neu initialisieren, da sporadisch Probleme nach dem Umschalten
      led_status = LOW; //da die Beatfrequenz neu gesetzt wird muss neu initialisiert werden
      return(1);
    }
    else return(2);
  }
}
//*********************************************************************************
void multi_led(int n) { //rot=sofort, gelb=min. 50% PV, gruen=100%PV, violett=Fehler
//                     rot,    gelb,   gruen,   blau,    violett
  byte neopix[5][3]={{0,10,0},{5,8,0},{10,0,0},{0,0,10},{0,5,8}}; // gedimmt, 255=maximum
//  byte neopix[5][3]={{0,64,0},{32,48,0},{64,0,0},{0,0,64},{0,32,48}}; //etwas hellere Variante
  pixels.setPixelColor(0, pixels.Color(neopix[n][0],neopix[n][1],neopix[n][2]));
  pixels.show(); 
}
//*********************************************************************************
// ein an/aus Zyklus der LED dauert 10000 us. Das Verhältnis an bzw. aus wird über 
// die Variable led_puls gesteuert. Die Dauer eines Zyklus in 10-facher MilliSekunden
// Zeit wird über n gesteuert (n=100  heisst ein Zyklus dauert 1000ms)
void led_beat(int n){
  unsigned long currentmicros = micros();
  if (currentmicros - led_previousmicros >= led_interval) {
    led_previousmicros = currentmicros;
    if (led_status == LOW) {
      led_status = HIGH;  // Note that this switches the LED *off*
      led_interval=10000;
    } 
    else {
      led_status = LOW; // Note that this switches the LED *on*
      if(led_flag==1) led_interval=led_puls *10000/n;
      else led_interval = 10000-(led_puls *10000/n);
    }
    //if(led_puls>n/4) led_puls=led_puls+4;
    led_puls++;
    if(led_puls>=n) {
      led_puls=0;
      led_flag=led_flag*(-1);
    }
    digitalWrite(LED_BUILTIN, led_status);
  }
}
//*********************************************************************************
int wallbox(char* param, int wert) {
  if(wb==1) return(go_echarger(param, wert)); //welche Wallbox ist auf der SD Karte aktiviert
  //else return(heidelberg(param, wert));
  else {
    int x=heidelberg(param, wert);
    if(x<-20000) {
      sprintf(telnet_buf,"                                                                                                                $$$$$$$$$$$$$$$FEHLER: %d\n\r",x );telnet_write(telnet_buf);
    }
    return(x);
  }
}
//*********************************************************************************
int heidelberg(char* param, int wert) { 
  int car=2;
  byte datacs[] = { 0x01, 0x04, 0x00, 0x05, 0x00, 0x01}; //chargingstate   
  byte datamc[] = { 0x01, 0x06, 0x01, 0x05, 0x00, 120}; //Strom setzen, 120 = 12A
  byte dataL1[] = { 0x01, 0x04, 0x00, 0x06, 0x00, 0x01}; //Strom_ist L1
  byte dataVA[] = { 0x01, 0x04, 0x00, 0x0E, 0x00, 0x01}; //Power in VA alle Phasen
  if((leistung=rs485_send_and_rec(dataVA,6))<=-30000) return(-30012);               // aktuelle Leistungsabgabe der Wallbox
  if((ladestrom_ist=rs485_send_and_rec(dataL1,6))<=-30000) return(-30011);          // immer den aktuellen Ladestrom abfragen, die Antwortlänge beträgt 6 Byte
  if(ladestrom_ist<1) {
    if((car=rs485_send_and_rec(datacs,6))<=-30000) return(-30009);                 // falls kein Ladestrom_ist dann abfragen ob Fahrzeug gesteckt, die Antwortlänge beträgt 6 Byte
    if(car==0x02) car=1;                                                           //entspricht dem car=1 beim go-eCharger
    else car=2;                                                                    //Wert egal, Hauptsache ungleich 1
  }
  if(param[1]=='l') {                                                              //'l' (l wie ludwig)kommt von "alw" Ladung starten wert=1 oder stoppen wert=0
    if(wert==1) {
      laden_aktiv=1;
      datamc[5]=ladestrom*10;
      if(rs485_send_and_rec(datamc,7)!=ladestrom*10) return(-30021);                //die Antwortlänge beträgt 7 Byte und enthält den gesetzten Ladestrom
    }
    else {
      laden_aktiv=0;
      datamc[5]=0;
      if(rs485_send_and_rec(datamc,7)!=0) return(-30010);                            //die Antwortlänge beträgt 7 Byte und enthält den gesetzten Ladestrom
     }
  }
  if(param[1]=='m') {                                                                //'m' kommt von "amx" = Ladestrom setzen,
    if(laden_aktiv==1 && wert >=6) {
      datamc[5]=wert*10; 
      if(rs485_send_and_rec(datamc,7)!=wert*10) return(-30010);                      //die Antwortlänge beträgt 7 Byte und enthält den gesetzten Ladestrom
    }
  }
  return(car);
}
//*********************************************************************************
int rs485_send_and_rec(byte* zu_senden, int anz)  { //in anz steht die länge der erwarteten Antwort
  unsigned int crc = 0xFFFF;                        //Wert ist bei RS485 Modbus zur CRC Prüfung definiert
  int wert=2; //auch wenn Box im Standby bzw.offline mit Fahrzeug nicht gesteckt zurück kommen
  for(int loop=0;loop<3;loop++) { //sporadisch wird keine Antwort empfangen, dann nocheinmal probieren
    //RS485 senden . . .
    int anz_temp=anz;
    for (unsigned int i = 0; i < 6; i++) crc = crc16(crc, zu_senden[i]); //es ist über sechs Byte CRC zu bilden
    digitalWrite(RS485_Richtung, HIGH);  
    Serial.flush();
    delay(100+loop*100); //bei jedem weiteren Versuch etwas länger warten
    sprintf(telnet_buf,"                                                                                                                Zeile344: ");telnet_write(telnet_buf);
    for( int j=0; j<6;j++) {                                            //es sind sechs Zeichen zu senden
      Serial.write( zu_senden[j]);
//      sprintf(telnet_buf,"0x%02x, ", zu_senden[j]);telnet_write(telnet_buf);
      sprintf(telnet_buf,"%02d, ", zu_senden[j]);telnet_write(telnet_buf);
    }
    Serial.write( crc%256);
    Serial.write( crc/256);
    Serial.flush(); 
    //delay(50); wenn dieses delay aktiv keine Antwort!!!
    digitalWrite(RS485_Richtung, LOW);
    //RS485 senden ist fertig, jetzt die Antwort auswerten ****************** 
    delay(20);// es ist alles gesendet, jetzt einen Moment warten bevor die Antwort gelesen wird
    crc = 0xFFFF; //crc neu initialisieren für die Antwortprüfung
    int anz_receive=Serial.available();
    sprintf(telnet_buf,"Empf:%d, loop:%d, ",anz_receive,loop); telnet_write(telnet_buf);
    while(Serial.available() > 0) {
      ArduinoOTA.handle(); //OTA OTA OTA OTA OTA OTA OTA OTA OTA OTA OTA OTA OTA OTA OTA
      byte b = Serial.read();
      if(anz_temp>=2) {
        crc = crc16(crc, b);
        //sprintf(telnet_buf,"0x%02x, ", b);telnet_write(telnet_buf);
        sprintf(telnet_buf,"%02d, ", b);telnet_write(telnet_buf);
      }
      if(anz_temp==3) wert=b*256;   //Wert der Antwort in Integer wandeln 
      if(anz_temp==2) wert=wert+b;  //Wert der Antwort in Integer wandeln
      if(anz_temp==1&&b!=(crc%256)) return(-30000); //CRC Fehler Low Byte
      if(anz_temp==0) {                             
        if(b!=(crc/256)) return(-30001);       //CRC Fehler High Byte
        sprintf(telnet_buf,"CRC: 0x%02x,0x%02x ",crc%256, crc/256); telnet_write(telnet_buf);
      }
      anz_temp--;
    }
    telnet_write("\n\r");
    if(anz_receive>0) break;
  }
  return(wert);
}
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

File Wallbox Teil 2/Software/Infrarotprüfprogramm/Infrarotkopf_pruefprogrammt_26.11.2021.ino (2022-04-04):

/*Infrarotkopfprüfprogramm
 * 
 * 
/LOG5LK13BE803039<\r><\n>
<\r><\n>
1-0:96.1.0*255(001LOG0065626430)<\r><\n>
1-0:1.8.0*255(000471.6452*kWh)<\r><\n>
1-0:2.8.0*255(000528.9178*kWh)<\r><\n>
1-0:0.2.0*255(ver.03,432F,20170504)<\r><\n>
1-0:96.90.2*255(0F66)<\r><\n>
1-0:97.97.0*255(00000000)<\r><\n>
!<\r><\n>
*/
#include <SoftwareSerial.h>  //Version 6.15.1
SoftwareSerial SoS;
#define LOGAREX 4 //D2 = GPIO4
//******************************************************************
void setup(){
  Serial.begin(9600);
  Serial.print("\n TEST TEST TEST   Zaehler LOGAREX über IR auslesen, alle 10 Sekunden, 13.11.2021\n");
  pinMode(LOGAREX, OUTPUT);
}
//******************************************************************
void loop(){
int v, e;
long n;
  n=zaehler_LOGAREX(&v, &e);
  if(n>=-200001) {
    Serial.print(v); Serial.print("=v  e=");Serial.print(e); Serial.print("    n=");Serial.println(n);
  }
}
//******************************************************************
long zaehler_LOGAREX(int *v, int *e){
  int v1= *v, e1= *e;
  long  r=-200002;
  static char puffer[227] ;
  static int m=0;
  static boolean flag=false, flag2=false;
  static unsigned long t=0;
    if(millis()-t > 10000) { //XXXXXXXXXXXXXXXXXXXXXXXXXXXXXX   10000
      //Serial.println("hier Uwe . . .");Serial.flush();
      if(flag==false) {
       // Serial.print("SoS Beginn,  ");//Serial.flush();
      //  SoS.begin(9600, SWSERIAL_8N1, D5, D6) ; //D5, D6 urspünglich
        flag=true;
        digitalWrite(LOGAREX, HIGH);

      }
      //if (SoS.available() > 0) {
      //  char c = SoS.read();
      if (Serial.available() > 0) {
        char c = Serial.read();
        if(c=='/' || m>225) { // '/' ist das erste Zeichen einer Ausgabe des Zaehlers
          //Serial.print("/ erkannt   ");
          m=0;      
          flag2=true;
        }
        if(flag2==true) {
          puffer[m++] = c; 
          if(c=='!') {        // '!' ist das letzte Zeichen einer Ausgabe des Zaehlers
       //     SoS.end();
            digitalWrite(LOGAREX, LOW);
            t=millis();
            flag=false;
            flag2=false;
            puffer_ausgeben(puffer);
            r = zaehler_aufbereiten(puffer, &v1, &e1);
            *v=v1;
            *e=e1;
          }
        }
      }
    }
  return r; 
}
//******************************************************************
void puffer_ausgeben(char *puffer){
  int n=0;
  while(true) {
    Serial.print(puffer[n]);
    if(puffer[n++]=='!') break;
  }
  Serial.print("\n");
}
long zaehler_aufbereiten(char *puffer, int *x, int *y) {
  static unsigned long e=0, e_alt=0, v=0, v_alt=0, t=0; //v = Verbrauch, e = Einspeisung
  static int n=0, v_in_W, e_in_W;
  long returnwert;
  v=zaehler_als_integer(69, puffer); //ab Position 69 im Puffer aufbereiten
  e=zaehler_als_integer(101,puffer);
  if(v==999999999 || e==999999999) {
    //Serial.println("\n\n XXXXXXXXXXXXXXXXXXXX   F  E  H  L  E  R\n\n");
    return(-200000);
  }
  else {
    v_in_W = (v-v_alt)*36*10000/(millis()-t); //alle 10 sekunden
    e_in_W = (-1)*int ((e-e_alt)*(36)*10000/(millis()-t)); // Einspeisung wird als negativ gerechnet
    Serial.print("\n Zeit _____ ");Serial.print(millis()-t);Serial.print(" ms, Verbrauch_ in_W: ");Serial.print(v_in_W); 
    Serial.print(", Verbrauch: ");Serial.print(v-v_alt);Serial.print("   v_alt:  ");Serial.print(v_alt);Serial.print("   EINSPEISUNG in W: ");
    Serial.print( e_in_W);Serial.print("   Einspeisung: ");Serial.println(e-e_alt);
    t=millis();
    returnwert=v_in_W+e_in_W; //Returnwert berechnen
    if(v_alt == 0) returnwert= -200001; //passiert beim allerersten Durchlauf und dann nie wieder
    v_alt=v;
    e_alt=e;
    *x=v_in_W;
    *y=e_in_W;
   }
   return (returnwert); 
}
//******************************************************************
unsigned long zaehler_als_integer(int pos, char *puffer) {
  unsigned long a=0, faktor=1000000000;
  for(int m=0; m<11;m++) {
    char c1=puffer[m+pos];
    if(c1!='.') {
      if( (c1<0x30 || c1>0x39) ) return(999999999); //einfache Plausibilitätsprüfung
      a=a+(c1 & 0x0F)*faktor;
      faktor = faktor/10;
    }
  }
  return(a);
}

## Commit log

2021-10-19 new version
    für Go-e ab der Softwareversion 051.4
2021-10-19 new version
    Go-e ab der Softwareversion 051.4
2022-04-04 Ergänzungen Teil 2
    [Wallboxsteuerung-WEMOS-ohne-shelly2.brd, Wallboxsteuerung-WEMOS-ohne-shelly2.sch]
